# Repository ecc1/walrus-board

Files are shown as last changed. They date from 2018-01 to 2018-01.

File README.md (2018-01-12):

# Walrus Board

Walrus is an open-source platform for battery-powered sub-GHz and 2.4 GHz radio communication

### Dual Radios

Walrus has two radios, accessed over SPI:

* [RFM69HCW transceiver](http://www.hoperf.com/rf_transceiver/modules/RFM69HCW.html)
  for 900 MHz (also usable at 433 MHz)
* [CC2500 transceiver](http://www.ti.com/product/CC2500)
  for 2.4 GHz

### Designed for Raspberry Pi Zero W

* Raspberry Pi Zero form factor
* 40-pin Raspberry Pi GPIO connector
* HAT EEPROM

Walrus board connected to Raspberry Pi Zero W

### Battery Power Management

* JST PH 2.0mm connector for 3.7 V LiPo battery
* 500 mA battery charging when Raspberry Pi is connected to 5 V via micro-USB
* hard power-off via pushbutton or GPIO disconnects battery from Raspberry Pi
* programmable power-on via RTC alarm

### Other Peripherals

Walrus has the following I2C devices:

* Real-Time Clock (M41T62LC) with power-on alarm
* Analog-Digital Converter (ADS1015) for battery voltage and charge current measurement
* 3-axis Accelerometer (LIS3DH) with single and double-tap detection

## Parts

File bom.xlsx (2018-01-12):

Quantity | DNI | Designator | Description | Comment | Case | Mfg1 | Mfg1PartNumber | Distributor | MDLPartNumber
1 |  | C1 | Ceramic Chip Capacitor | 1.0µF 16V X7R | 1608(0603) | Taiyo Yuden | EMK107B7105KA-T | https://www.digikey.com/product-detail/en/taiyo-yuden/EMK107B7105KA-T/587-1241-1-ND/931018 | CAP_000045
2 |  | C8, C9 | Ceramic Chip Capacitor | 4.7µF 6.3V X5R | 1005(0402) | Murata | GRM155R60J475ME87D | https://www.digikey.com/product-detail/en/murata-electronics-north-america/GRM155R60J475ME87D/490-5408-1-ND/2175215 | CAP_000063
1 |  | C11 | Ceramic Chip Capacitor | 1.0µF 10V X5R | 1005(0402) | AVX | 0402ZD105KAT2A | https://www.digikey.com/product-detail/en/avx-corporation/0402ZD105KAT2A/478-4596-1-ND/1645907 | CAP_000094
2 |  | C2, C5 | Ceramic Chip Capacitor | 2.2µF 16V X5R | 1005(0402) | TDK | C1005X5R1C225K050BC | https://www.digikey.com/product-detail/en/tdk-corporation/C1005X5R1C225K050BC/445-9085-1-ND/3661600 | CAP_000166
2 |  | C20, C21 | Ceramic Chip Capacitor | 15pF 50V C0G/NP0 | 1005(0402) | AVX | 04025A150GAT2A | https://www.digikey.com/product-detail/en/avx-corporation/04025A150GAT2A/478-5268-1-ND/1950935 | CAP_000179
2 |  | C412, C512 | Ceramic Chip Capacitor | 47pF 50V C0G/NP0 | 1005(0402) | Kemet | C0402C470K5GACTU | https://www.digikey.com/product-detail/en/kemet/C0402C470K5GACTU/399-7796-1-ND/3471519 | CAP_000193
2 |  | C121, C131 | Ceramic Chip Capacitor | 100pF 50V C0G/NP0 | 1005(0402) | Murata | GRM1555C1H101JA01D | https://www.digikey.com/product-detail/en/murata-electronics-north-america/GRM1555C1H101JA01D/490-5922-1-ND/3721279 | CAP_000202
1 |  | C123 | Ceramic Chip Capacitor | 1.8pF 50V C0G/NP0 | 1005(0402) | Murata | GRM1555C1H1R8CA01D | https://www.digikey.com/product-detail/en/murata-electronics-north-america/GRM1555C1H1R8CA01D/490-5898-1-ND/3569084 | CAP_000204
1 |  | C124 | Ceramic Chip Capacitor | 1.5pF 50V C0G/NP0 | 1005(0402) | Murata | GRM1555C1H1R5CA01D | https://www.digikey.com/product-detail/en/murata-electronics-north-america/GRM1555C1H1R5CA01D/490-5891-1-ND/3481884 | CAP_000205
2 |  | C122, C132 | Ceramic Chip Capacitor | 1.0pF 50V C0G/NP0 | 1005(0402) | Murata | GRM1555C1H1R0CA01D | https://www.digikey.com/product-detail/en/murata-electronics-north-america/GRM1555C1H1R0CA01D/490-3199-1-ND/702740 | CAP_000206
3 |  | C91, C151, C181 | Ceramic Chip Capacitor | 220pF 50V X7R | 1005(0402) | Murata | GRM155R71H221KA01D | https://www.digikey.com/product-detail/en/murata-electronics-north-america/GRM155R71H221KA01D/490-1298-1-ND/587937 | CAP_000207
12 |  | C3, C4, C6, C7, C10, C12, C13, C14, C41, C51, C111, C141 | Ceramic Chip Capacitor | 0.1µF 10V X7R | 1005(0402) | Murata | GRM155R71A104KA01D | https://www.digikey.com/product-detail/en/murata-electronics-north-america/GRM155R71A104KA01D/490-6321-1-ND/3845518 | CAP_000208
1 | ♦ | J5 | KK 100 HEADER ASSY FLAT VERTICAL BREAKAWAY, 1X2 | 22-28-4023 |  | Molex | 22-28-4023 |  | CONN_000017
2 |  | J1, J2 | Ultra Small Surface Mount Coaxial Connectors - 1.9mm or 2.4mm Mated Height | U.FL-R-SMT-1 |  | Hirose | U.FL-R-SMT-1 | https://www.digikey.com/product-detail/en/hirose-electric-co-ltd/U.FL-R-SMT-1(10)/H11891CT-ND/2504612 | CONN_000064
1 |  | J4 | PH CONNECTOR/2.0MM Pitch Side Entry | S2B-PH-SM4-TB |  | JST | S2B-PH-SM4-TB | https://www.digikey.com/product-detail/en/jst-sales-america-inc/S2B-PH-SM4-TB(LF)(SN)/455-1749-1-ND/926846 | CONN_000190
1 | ♦ | J3 | 0.100" Tiger Beam™ Cost-effective Single Beam Socket Strip | HLE-120-02-G-DV-A |  | Samtec | HLE-120-02-G-DV-A |  | CONN_000192
8 |  | D1, D2, D3, D4, D5, D7, D10, D11 | Schottky Barrier Diode | RB520S30T1G | SOD-523 | ON Seminconductor | RB520S30T1G | https://www.digikey.com/product-detail/en/on-semiconductor/RB520S30T1G/RB520S30T1GOSCT-ND/964626 | DIOD_000001
1 |  | D9 | Surface Mounting Chip LED | BLUE | 1608(0603) | Lite-On | LTST-C190TBKT | https://www.digikey.com/product-detail/en/lite-on-inc/LTST-C190TBKT/160-1646-1-ND/573586 | DIOD_000059
1 |  | D6 | Surface Mounting Chip LED | GREEN | 1608(0603) | Lite-On | LTST-C190KGKT | https://www.digikey.com/product-detail/en/lite-on-inc/LTST-C190KGKT/160-1435-1-ND/386814 | DIOD_000061
1 |  | D8 | Surface Mounting Chip LED | RED | 1608(0603) | Lite-On | LTST-C190CKT | https://www.digikey.com/product-detail/en/lite-on-inc/LTST-C190CKT/160-1181-1-ND/269253 | DIOD_000068
1 |  | FB1 | GHz Noise Suppression Chip Ferrite Bead | 1000ohms ±25% @100MHz | 1005(0402) | Murata | BLM15HG102SN1D | https://www.digikey.com/product-detail/en/murata-electronics-north-america/BLM15HG102SN1D/490-3999-1-ND/1016259 | FB_000009
3 | ♦ | FD1, FD2, FD3 | Fiducial, PCB Printed Copper Feature | Fiducial, Single Side, 0.75mm Land |  |  |  |  | FD_000001
1 |  | F1 | POLY-FUSE® Resettable PTC, Surface Mount > LoRho Series | 0.75A Hold,1.5A Trip | 1608(0603) | Littelfuse | 0603L075SLYR | https://www.digikey.com/product-detail/en/littelfuse-inc/0603L075SLYR/F5777CT-ND/3661919 | FUSE_000007
1 |  | U9 | MEMS digital output motion sensor: ultra low-power high performance 3-axes “nano” accelerometer | LIS3DH | LGA-16 | STMicroelectronics | LIS3DH | https://www.digikey.com/product-detail/en/stmicroelectronics/LIS3DHTR/497-10613-1-ND/2334355 | IC_000038
1 |  | U5 | USB-FRIENDLY LITHIUM-ION BATTERY CHARGER AND POWER-PATH MANAGEMENT IC | bq24232 | QFN16 | Texas Instruments | BQ24232RGT | https://www.digikey.com/product-detail/en/texas-instruments/BQ24232RGTR/296-41207-1-ND/5222663 | IC_000195
1 |  | U3 | Ultra-Small, Low-Power, I2C-Compatible, 3.3-kSPS, 12-Bit ADC With Internal Reference, Oscillator, and Programmable Comparator | ADS1015 | X2QFN | Texas Instruments | ADS1015IRUGR,ADS1015IRUGT | https://www.digikey.com/product-detail/en/texas-instruments/ADS1015IRUGR/296-43557-1-ND/5864781 | IC_000284
1 |  | U2 | ISM TRANSCEIVER MODULE | RFM69HCW | MODULE | HopeRF | RFM69HCW | https://www.sparkfun.com/products/13909 | IC_000286
1 |  | U1 | Low-Cost Low-Power 2.4 GHz RF Transceiver | CC2500 | QFN20 | Texas Instruments | CC2500RGP,CC2500RGPR | https://www.digikey.com/product-detail/en/texas-instruments/CC2500RGPR/296-38562-1-ND/5034436 | IC_000287
1 |  | U7 | 2.6A Low Loss Ideal Diode in ThinSOT | LTC4411 | TSOT23-5 | Linear Technology | LTC4411ES5 | https://www.digikey.com/product-detail/en/linear-technology/LTC4411ES5-TRMPBF/LTC4411ES5-TRMPBFCT-ND/1754256 | IC_000293
1 |  | U6 | Pushbutton On/Off Controller with Automatic Turn-On | LTC2955T-2 | TSOT23-8 | Linear Technology | TC2955CTS8-2#TRMPBF | https://www.digikey.com/product-detail/en/linear-technology/LTC2955CTS8-2-TRMPBF/LTC2955CTS8-2-TRMPBFCT-ND/3065187 | IC_000294
1 |  | U4 | Low-power serial real-time clock (RTCs) with alarm | M41T62LC | LCC-8 | STMicroelectronics | M41T62LC6F | https://www.digikey.com/product-detail/en/stmicroelectronics/M41T62LC6F/497-11275-1-ND/2673274 | IC_000295
1 |  | U8 | 32-Kb I2C CMOS Serial EEPROM | CAT24C32 | UDFN-8 | ON Seminconductor | CAT24C32HU4I−GT3 | https://www.digikey.com/product-detail/en/on-semiconductor/CAT24C32HU4I-GT3/CAT24C32HU4I-GT3OSCT-ND/4927901 | IC_000300
3 |  | L121, L122, L131 | Surface Mount Multilayer RF Chip Inductors | 1.2nH ±0.3nH | 1005(0402) | Murata | LQG15HS1N2S02D | https://www.digikey.com/product-detail/en/murata-electronics-north-america/LQG15HS1N2S02D/490-2611-1-ND/662891 | IND_000048
3 |  | R13, R17, R20 | Chip Resistor, Thick Film | 4.99K ±1% | 1005(0402) | Vishay/Dale | CRCW04024K99FKED | https://www.digikey.com/product-detail/en/vishay-dale/CRCW04024K99FKED/541-4.99KLCT-ND/1183202 | RES_000003
2 |  | R7, R14 | Chip Resistor, Thick Film | 10.0K ±1% | 1005(0402) | Vishay/Dale | CRCW040210K0FKED | https://www.digikey.com/product-detail/en/vishay-dale/CRCW040210K0FKED/541-10.0KLCT-ND/1183237 | RES_000005
4 | ♦ | R8, R9, R10, R12 | Chip Resistor, Thick Film | DNP | 1005(0402) |  |  |  | RES_000064
4 |  | R1, R2, R22, R23 | Chip Resistor, Thick Film | 100K ±1% | 1005(0402) | Vishay/Dale | CRCW0402100KFKED | https://www.digikey.com/product-detail/en/vishay-dale/CRCW0402100KFKED/541-100KLCT-ND/1183351 | RES_000067
1 |  | R15 | Chip Resistor, Thick Film | 680K ±1% | 1005(0402) | Vishay/Dale | CRCW0402680KFKED | https://www.digikey.com/product-detail/en/vishay-dale/CRCW0402680KFKED/541-680KLCT-ND/1183446 | RES_000103
1 |  | R21 | Chip Resistor, Thick Film | 22.0 ±1% | 1005(0402) | Vishay/Dale | CRCW040222R0FKED | https://www.digikey.com/product-detail/en/vishay-dale/CRCW040222R0FKED/541-22.0LCT-ND/1182931 | RES_000158
1 |  | R16 | Chip Resistor, Thick Film | 240K ±1% | 1005(0402) | Vishay/Dale | CRCW0402240KFKED | https://www.digikey.com/product-detail/en/vishay-dale/CRCW0402240KFKED/541-240KLCT-ND/1183392 | RES_000165
1 |  | R171 | Chip Resistor, Thick Film | 56K ±1% | 1005(0402) | Vishay/Dale | CRCW040256K0FKED | https://www.digikey.com/product-detail/en/vishay-dale/CRCW040256K0FKED/541-56.0KLCT-ND/1183322 | RES_000185
1 |  | R4 | Chip Resistor, Thick Film | 3.40K ±1% | 1005(0402) | Vishay/Dale | CRCW04023K40FKED | https://www.digikey.com/product-detail/en/vishay-dale/CRCW04023K40FKED/541-3.40KLCT-ND/1183182 | RES_000253
1 |  | R19 | Chip Resistor, Thick Film | 160 ±1% | 1005(0402) | Vishay/Dale | CRCW0402160RFKED | https://www.digikey.com/product-detail/en/vishay-dale/CRCW0402160RFKED/541-160LCT-ND/1183030 | RES_000286
1 |  | R18 | Chip Resistor, Thick Film | 191 ±1% | 1005(0402) | Vishay/Dale | CRCW0402191RFKED | https://www.digikey.com/product-detail/en/vishay-dale/CRCW0402191RFKED/541-191LCT-ND/1183039 | RES_000287
7 |  | R5, R6, R11, R24, R25, R26, R27 | Chip Resistor, Thick Film | 1.8K ±1% | 1005(0402) | Vishay/Dale | CRCW04021K80FKED | https://www.digikey.com/product-detail/en/vishay-dale/CRCW04021K80FKED/541-1.80KLCT-ND/1183150 | RES_000288
1 |  | R3 | Chip Resistor, Thick Film | 3.6K ±1% | 1005(0402) | Vishay/Dale | CRCW04023K60FKED | https://www.digikey.com/product-detail/en/vishay-dale/CRCW04023K60FKED/541-3.60KLCT-ND/1183185 | RES_000296
1 |  | S1 | KMR 2 Series Microminiature SMT Top Actuated | KMR221GLFS |  | C&K | KMR221GLFS | https://www.digikey.com/product-detail/en/c-k/KMR221GLFS/401-1427-1-ND/550466 | SWCH_000001
7 | ♦ | TP1, TP2, TP3, TP4, TP5, TP6, TP7 | Test Point | Test Point, Through Hole, 1.0mm Pad, 0.5mm Hole |  |  |  |  | TP_000015
1 |  | Q2 | Small Signal MOSFET | NTA4151PT1G | SOT416, SC75 | ON Seminconductor | NTA4151PT1G | https://www.digikey.com/product-detail/en/on-semiconductor/NTA4151PT1G/NTA4151PT1GOSCT-ND/687112 | TRAN_000001
2 |  | Q1, Q3 | Small Signal MOSFET | NTA7002NT1G | SOT416, SC75 | ON Seminconductor | NTA7002NT1G | https://www.digikey.com/product-detail/en/on-semiconductor/NTA7002NT1G/NTA7002NT1GOSCT-ND/1484663 | TRAN_000002
1 |  | Y1 | CERAMIC SMD CRYSTAL | 26.000MHz ±10ppm 10pF | XTAL5032 | Abracon | ABM3B-26.000MHZ-10-1-U-T | https://www.digikey.com/product-detail/en/abracon-llc/ABM3B-26.000MHZ-10-1-U-T/300-8219-1-ND/687912 | XTAL_000024

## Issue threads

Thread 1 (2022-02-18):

LIS3DH footprint

iceberg1369, 2022-02-18:
I would like to know do you have any trouble in soldering lis3dh by stencil and pick and place machine?

ecc1, 2022-02-18:
We used a contract assembly house to build the first (and only) run of Walrus boards. I don't think any of the components presented any difficulties.

Closed 2022-02-18.

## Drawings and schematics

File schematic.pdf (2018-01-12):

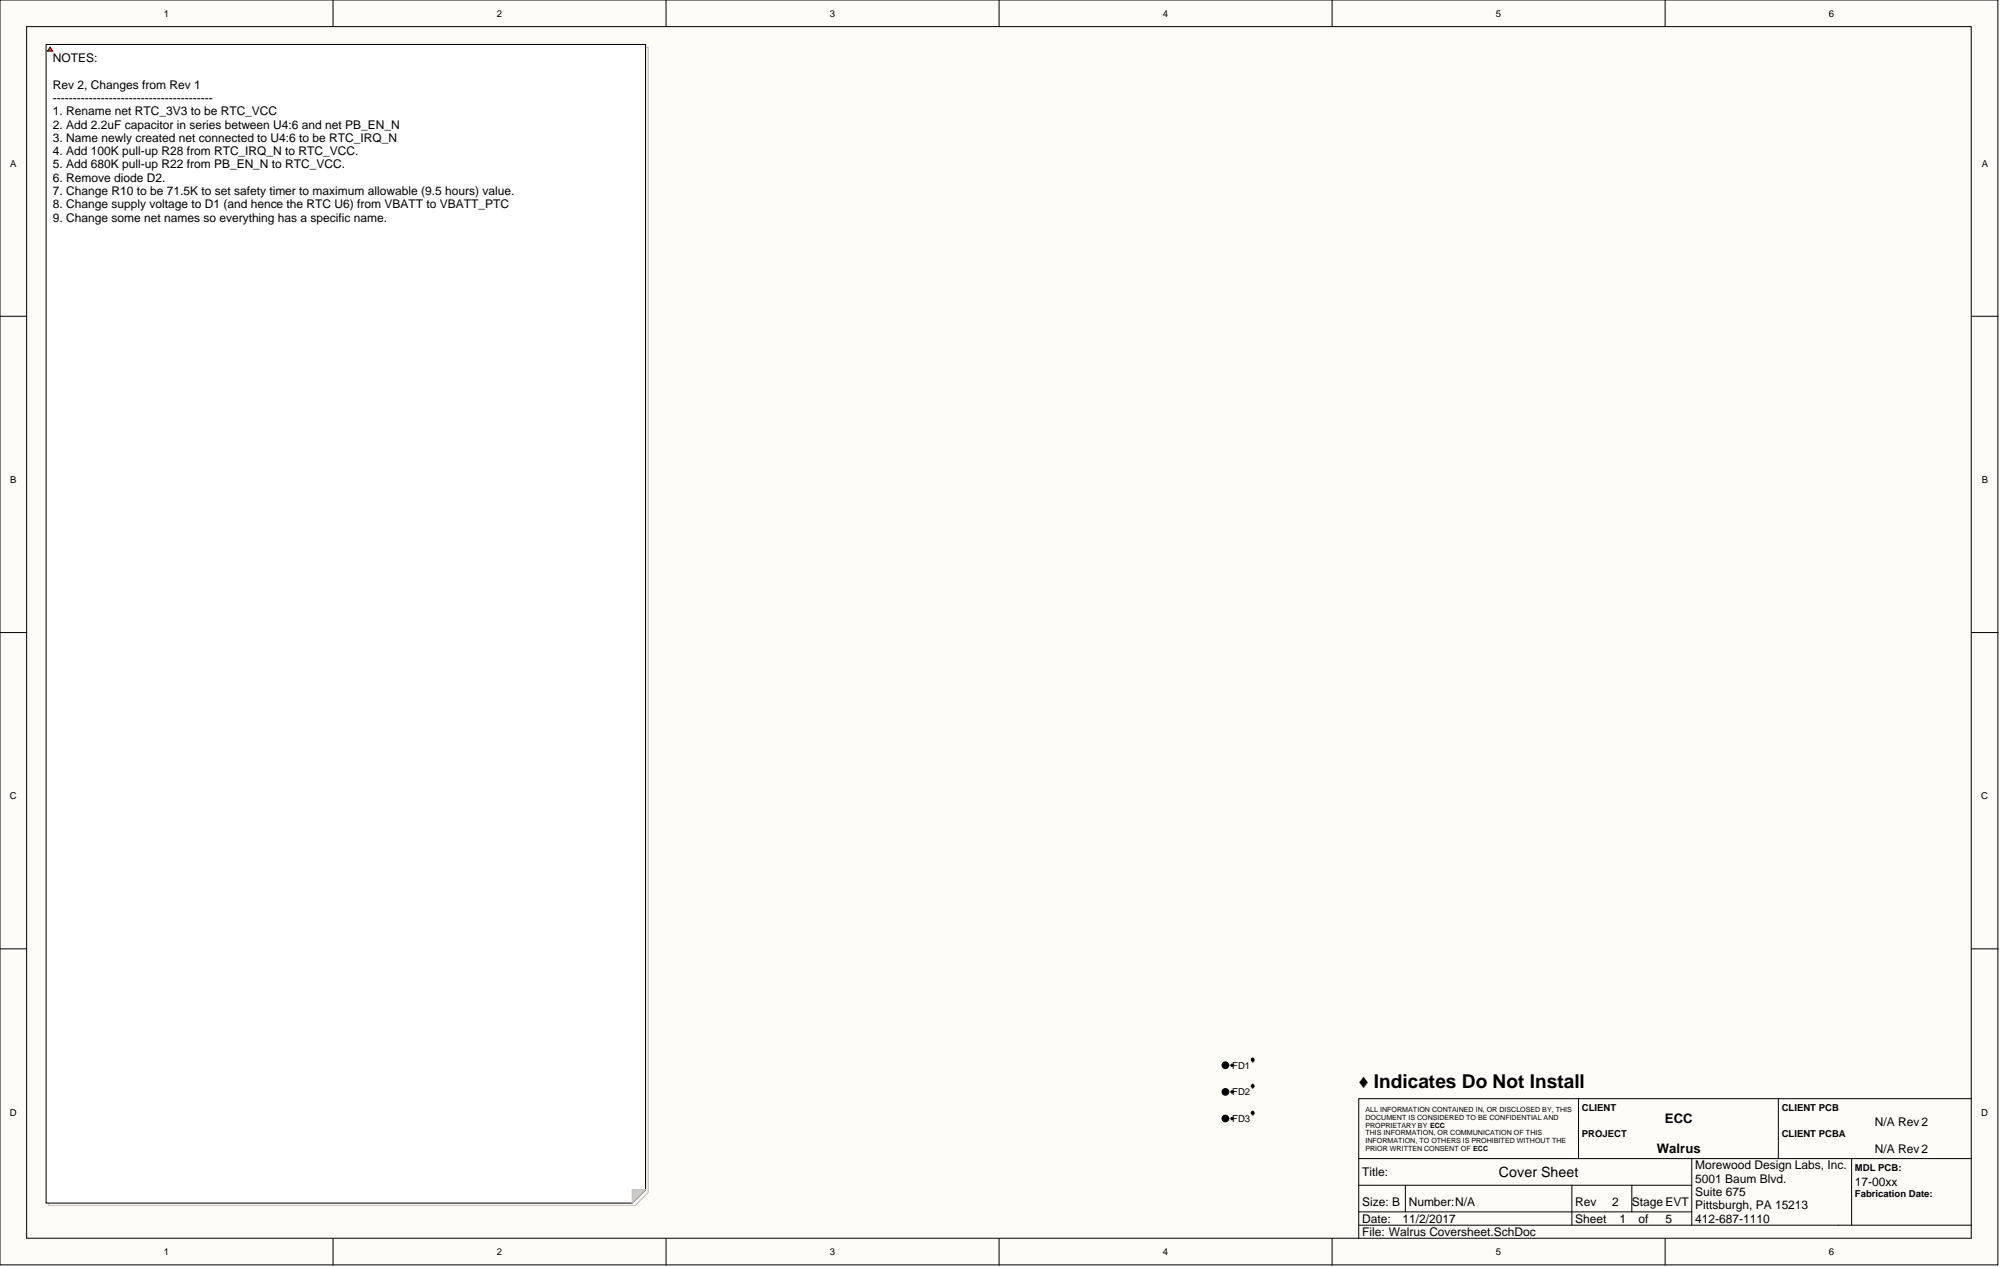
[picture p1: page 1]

Rev 2, Changes from Rev 1
1. Rename net RTC_3V3 to be RTC_VCC
2. Add 2.2uF capacitor in series between U4:6 and net PB_EN_N
3. Name newly created net connected to U4:6 to be RTC_IRQ_N
4. Add 100K pull-up R28 from RTC_IRQ_N to RTC_VCC.
5. Add 680K pull-up R22 from PB_EN_N to RTC_VCC.
6. Remove diode D2.
7. Change R10 to be 71.5K to set safety timer to maximum allowable (9.5 hours) value.
8. Change supply voltage to D1 (and hence the RTC U6) from VBATT to VBATT_PTC
9. Change some net names so everything has a specific name.

♦ Indicates Do Not Install

ALL INFORMATION CONTAINED IN, OR DISCLOSED BY, THIS PROPRIETARY BY DOCUMENT IS CONSIDERED TO BE CONFIDENTIAL AND ECC THIS INFORMATION, OR COMMUNICATION OF THIS INFORMATION, TO OTHERS IS PROHIBITED WITHOUT THE PRIOR WRITTEN CONSENT OF ECC | ECC CLIENT PROJECT Walrus | CLIENT PCB N/A CLIENT PCBA Rev 2 N/A Rev 2

Title: Cover Sheet | Morewood Design Labs, Inc. 5001 Baum Blvd. Suite 675 Pittsburgh, PA 15213 412-687-1110 | MDL PCB: 17-00xx Fabrication Date:

Size: B | Number: N/A | Rev 2 | Stage EVT
Date: | | Sheet 1 of 5

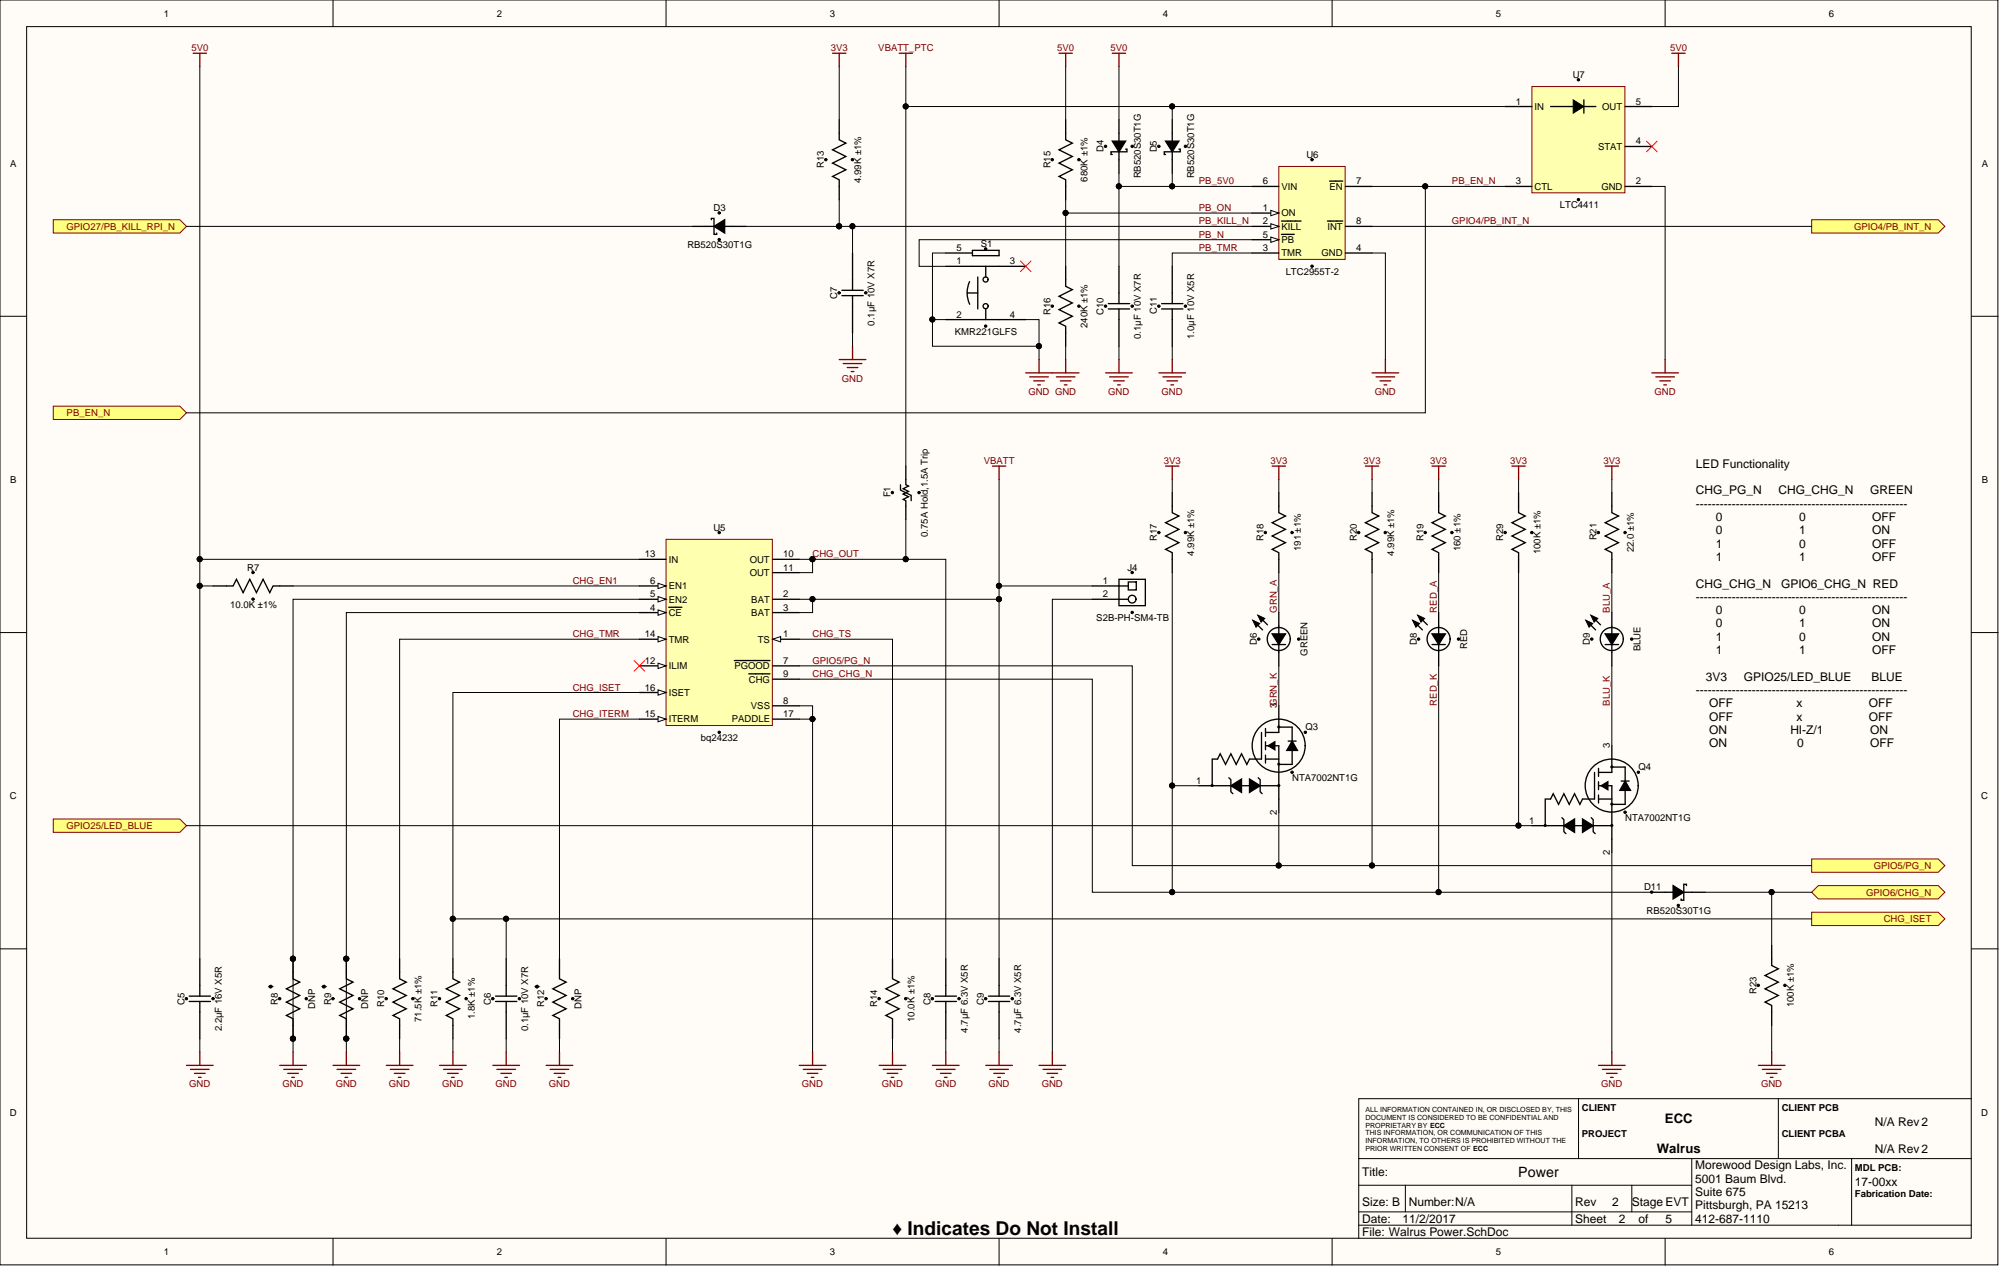
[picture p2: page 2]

GND | | PB_ON | INT | 8 ON 1

PB_KILL_N PB_N | KILL 2 PB 5

5 S1 | | PB_TMR | TMR 3

CE 4 | CHG_TS

CHG_TMR | TMR 14

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

Power

♦ Indicates Do Not Install

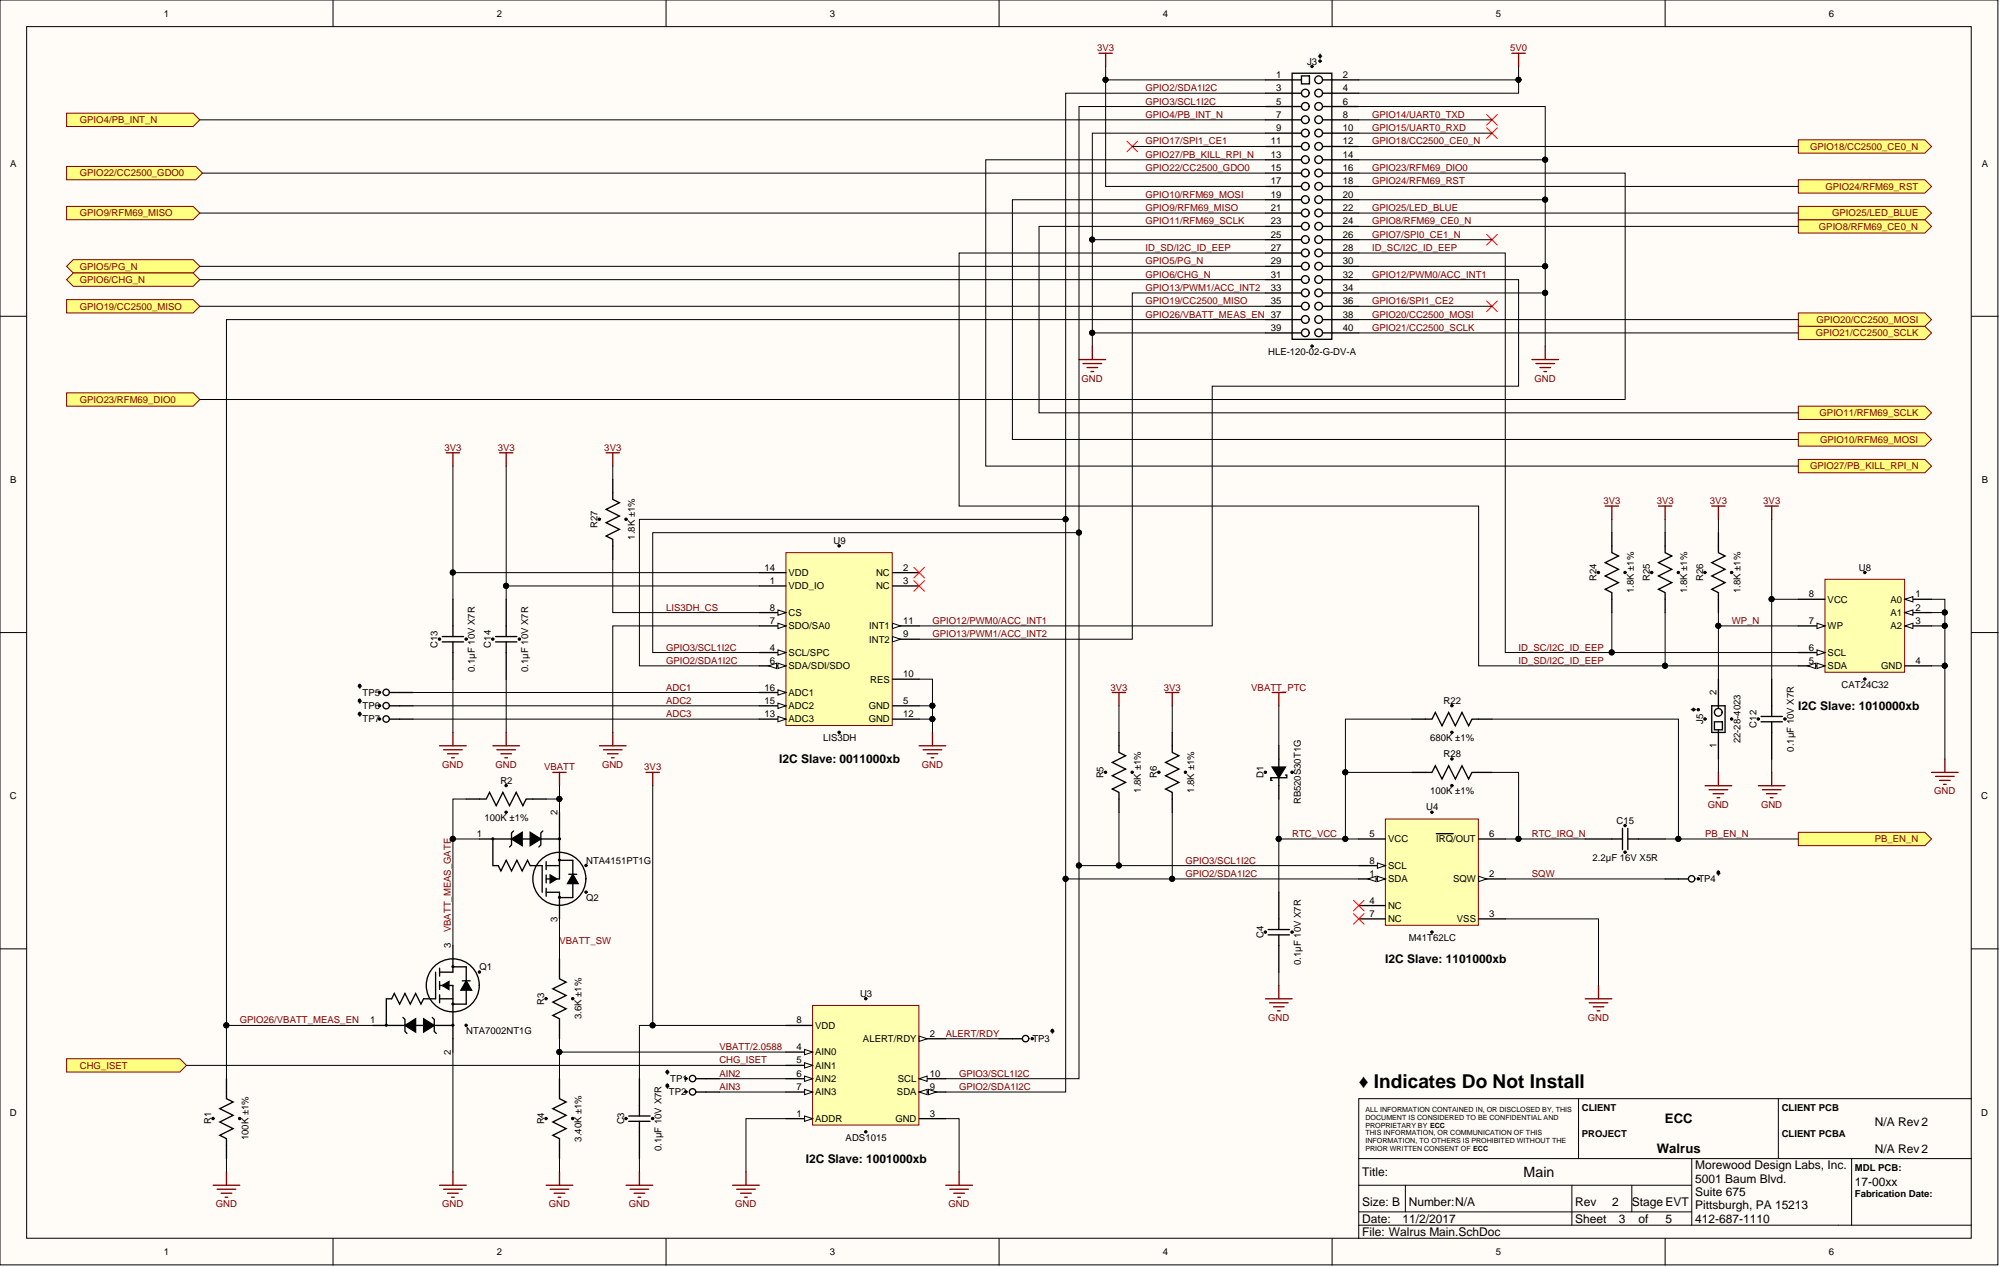
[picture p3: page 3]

GPIO2/SDA1I2C
GPIO3/SCL1I2C
GPIO4/PB_INT_N

GPIO17/SPI1_CE1 GPIO27/PB_KILL_RPI_N | 11

GPIO22/CC2500_GDO0 | 15 | 16 GPIO23/RFM69_DIO0

GPIO9/RFM69_MISO | 21 | | 22 GPIO25/LED_BLUE 24 GPIO8/RFM69_CE0_N
GPIO11/RFM69_SCLK | 23

ID_SD/I2C_ID_EEP | 27
GPIO5/PG_N | 29
GPIO6/CHG_N | 31
GPIO13/PWM1/ACC_INT2 | 33
GPIO19/CC2500_MISO | 35
GPIO26/VBATT_MEAS_EN | 37

GPIO3/SCL1I2C | SCL/SPC 4 | GPIO13/PWM1/ACC_INT2

ADC2 | ADC2 15
ADC3

♦ Indicates Do Not Install

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

Main

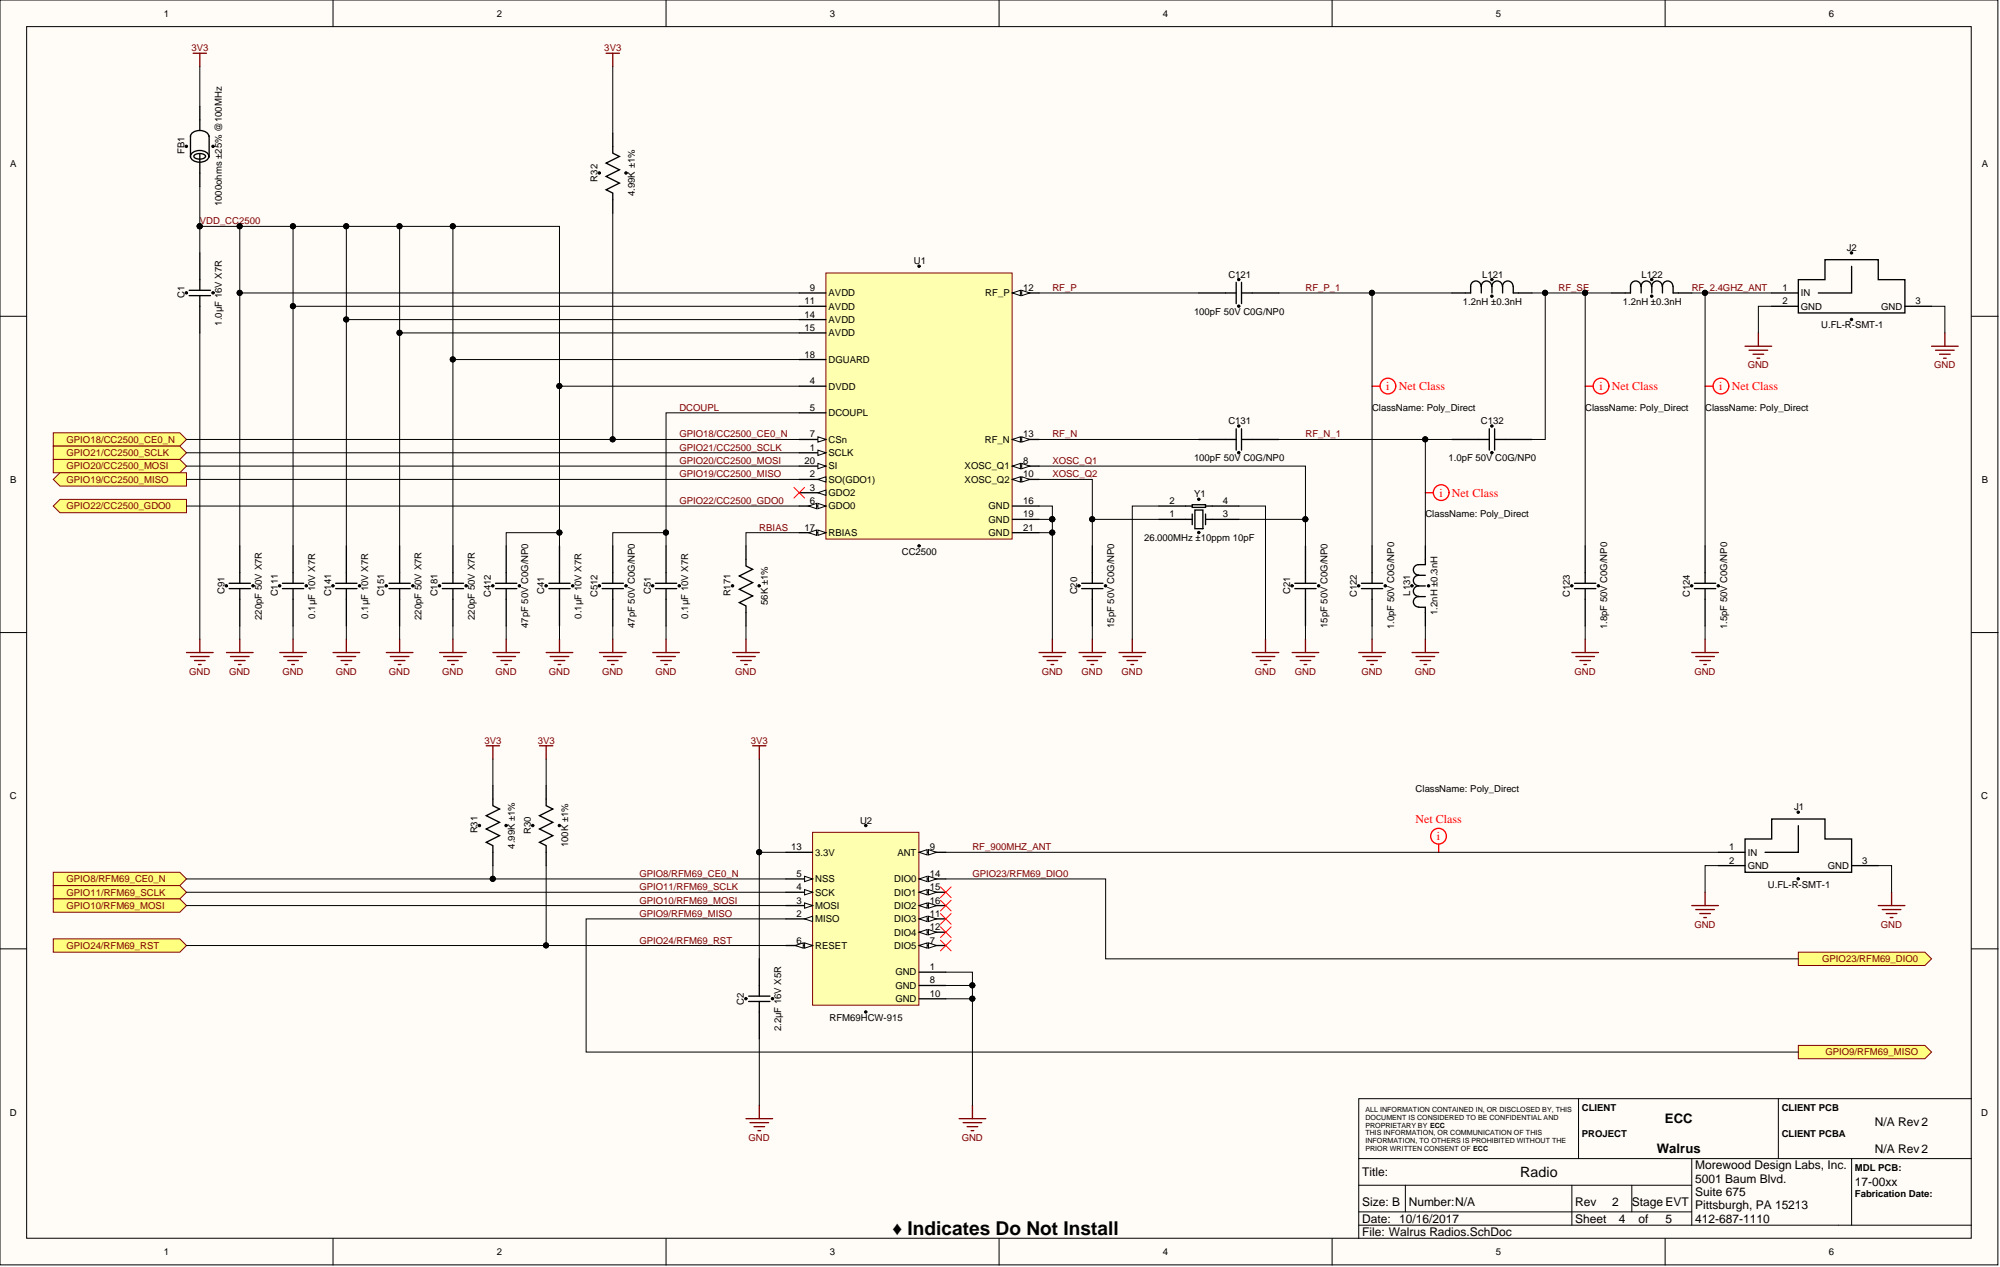
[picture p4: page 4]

AVDD 11
AVDD 14
AVDD 15

DGUARD 18

DVDD 4

DCOUPL | DCOUPL 5

GPIO18/CC2500_CE0_N | CSn 7
GPIO21/CC2500_SCLK | SCLK 1 | XOSC_Q1
GPIO20/CC2500_MOSI | SI 20

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

Radio

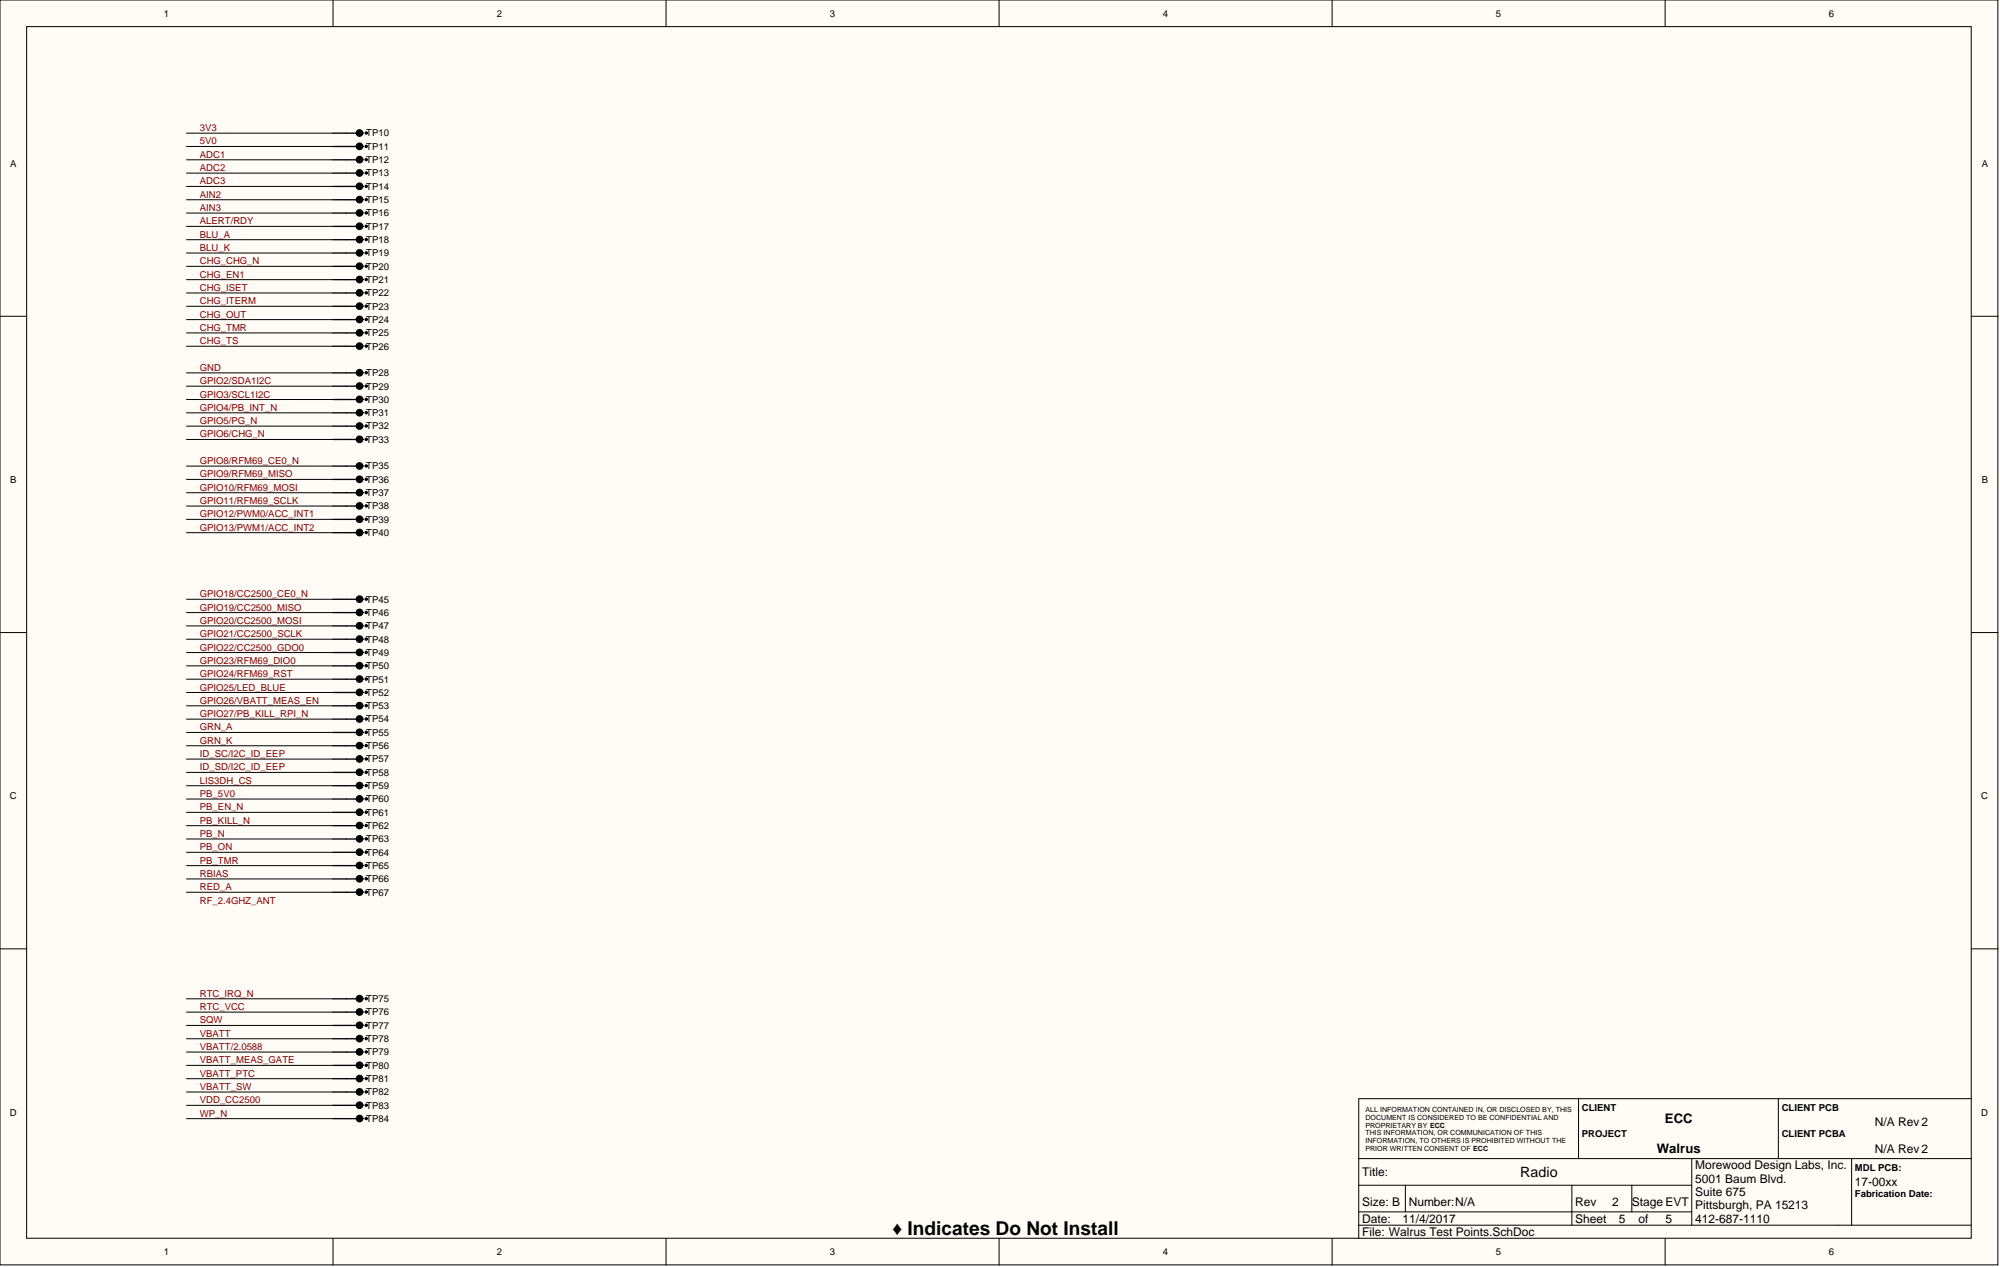
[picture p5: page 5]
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

Radio

Walrus Test Points.SchDoc

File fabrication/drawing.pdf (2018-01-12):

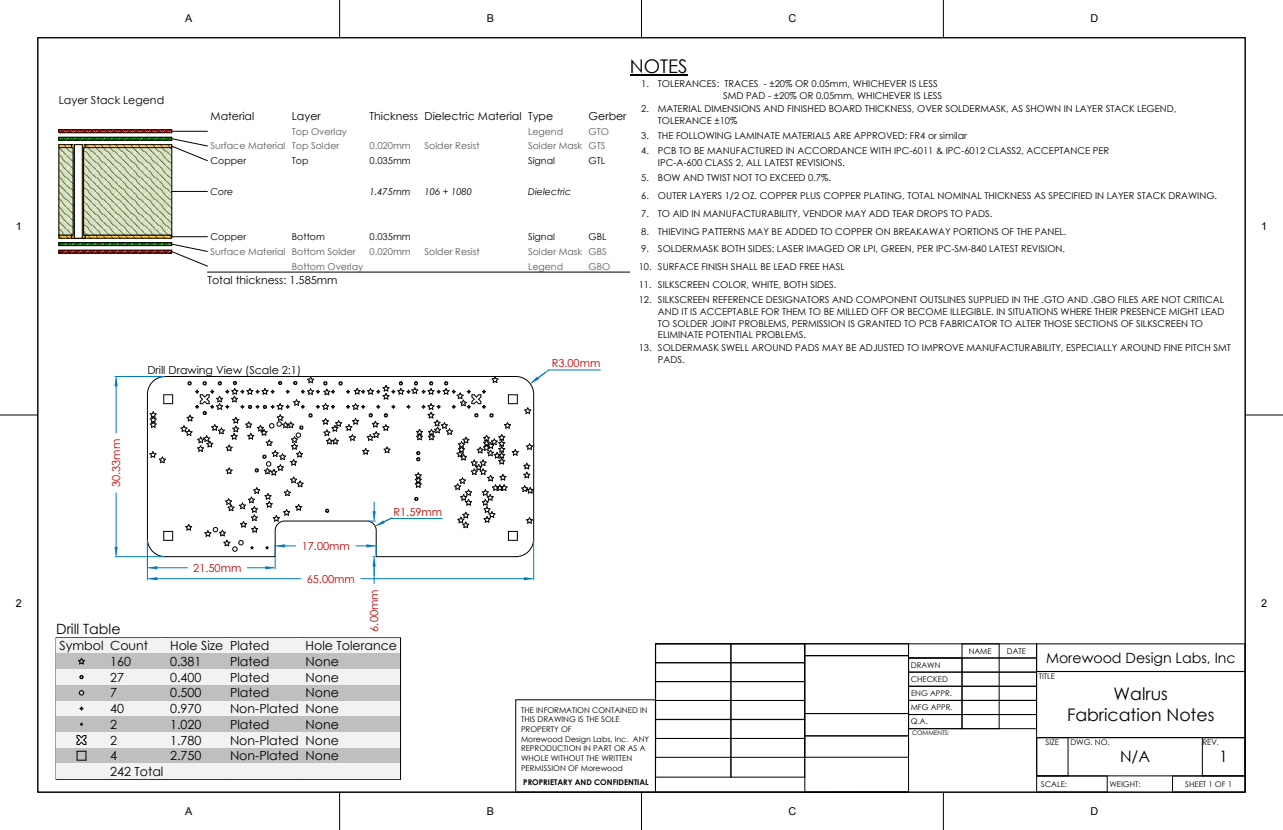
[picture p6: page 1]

TOLERANCES: TRACES - ±20% OR 0.05mm, WHICHEVER IS LESS

SMD PAD - ±20% OR 0.05mm, WHICHEVER IS LESS

MATERIAL DIMENSIONS AND FINISHED BOARD THICKNESS, OVER SOLDERMASK, AS SHOWN IN LAYER STACK LEGEND,
TOLERANCE ±10%
3. THE FOLLOWING LAMINATE MATERIALS ARE APPROVED: FR4 or similar
PCB TO BE MANUFACTURED IN ACCORDANCE WITH IPC-6011 & IPC-6012 CLASS2, ACCEPTANCE PER
IPC-A-600 CLASS 2, ALL LATEST REVISIONS.
5. BOW AND TWIST NOT TO EXCEED 0.7%.
6. OUTER LAYERS 1/2 OZ. COPPER PLUS COPPER PLATING, TOTAL NOMINAL THICKNESS AS SPECIFIED IN LAYER STACK DRAWING.
7. TO AID IN MANUFACTURABILITY, VENDOR MAY ADD TEAR DROPS TO PADS.
8. THIEVING PATTERNS MAY BE ADDED TO COPPER ON BREAKAWAY PORTIONS OF THE PANEL.
9. SOLDERMASK BOTH SIDES: LASER IMAGED OR LPI, GREEN, PER IPC-SM-840 LATEST REVISION.
10. SURFACE FINISH SHALL BE LEAD FREE HASL
11. SILKSCREEN COLOR, WHITE, BOTH SIDES.
SILKSCREEN REFERENCE DESIGNATORS AND COMPONENT OUTSLINES SUPPLIED IN THE .GTO AND .GBO FILES ARE NOT CRITICAL
AND IT IS ACCEPTABLE FOR THEM TO BE MILLED OFF OR BECOME ILLEGIBLE. IN SITUATIONS WHERE THEIR PRESENCE MIGHT LEAD
TO SOLDER JOINT PROBLEMS, PERMISSION IS GRANTED TO PCB FABRICATOR TO ALTER THOSE SECTIONS OF SILKSCREEN TO
ELIMINATE POTENTIAL PROBLEMS.
SOLDERMASK SWELL AROUND PADS MAY BE ADJUSTED TO IMPROVE MANUFACTURABILITY, ESPECIALLY AROUND FINE PITCH SMT
PADS.

Drill Drawing View (Scale 2:1)

Symbol | Count | Hole Size | Plated | Hole Tolerance

NAME | DATE | Morewood Design Labs, Inc

160 | 0.381 | Plated | None

DRAWN

THE INFORMATION CONTAINED IN
THIS DRAWING IS THE SOLE
PROPERTY OF
Morewood Design Labs, Inc. ANY
REPRODUCTION IN PART OR AS A
WHOLE WITHOUT THE WRITTEN
PERMISSION OF Morewood
PROPRIETARY AND CONFIDENTIAL

2 | 1.780 | Non-Plated | None
4 | 2.750 | Non-Plated | None
242 Total

SIZE | DWG. NO. N/A | REV. 1

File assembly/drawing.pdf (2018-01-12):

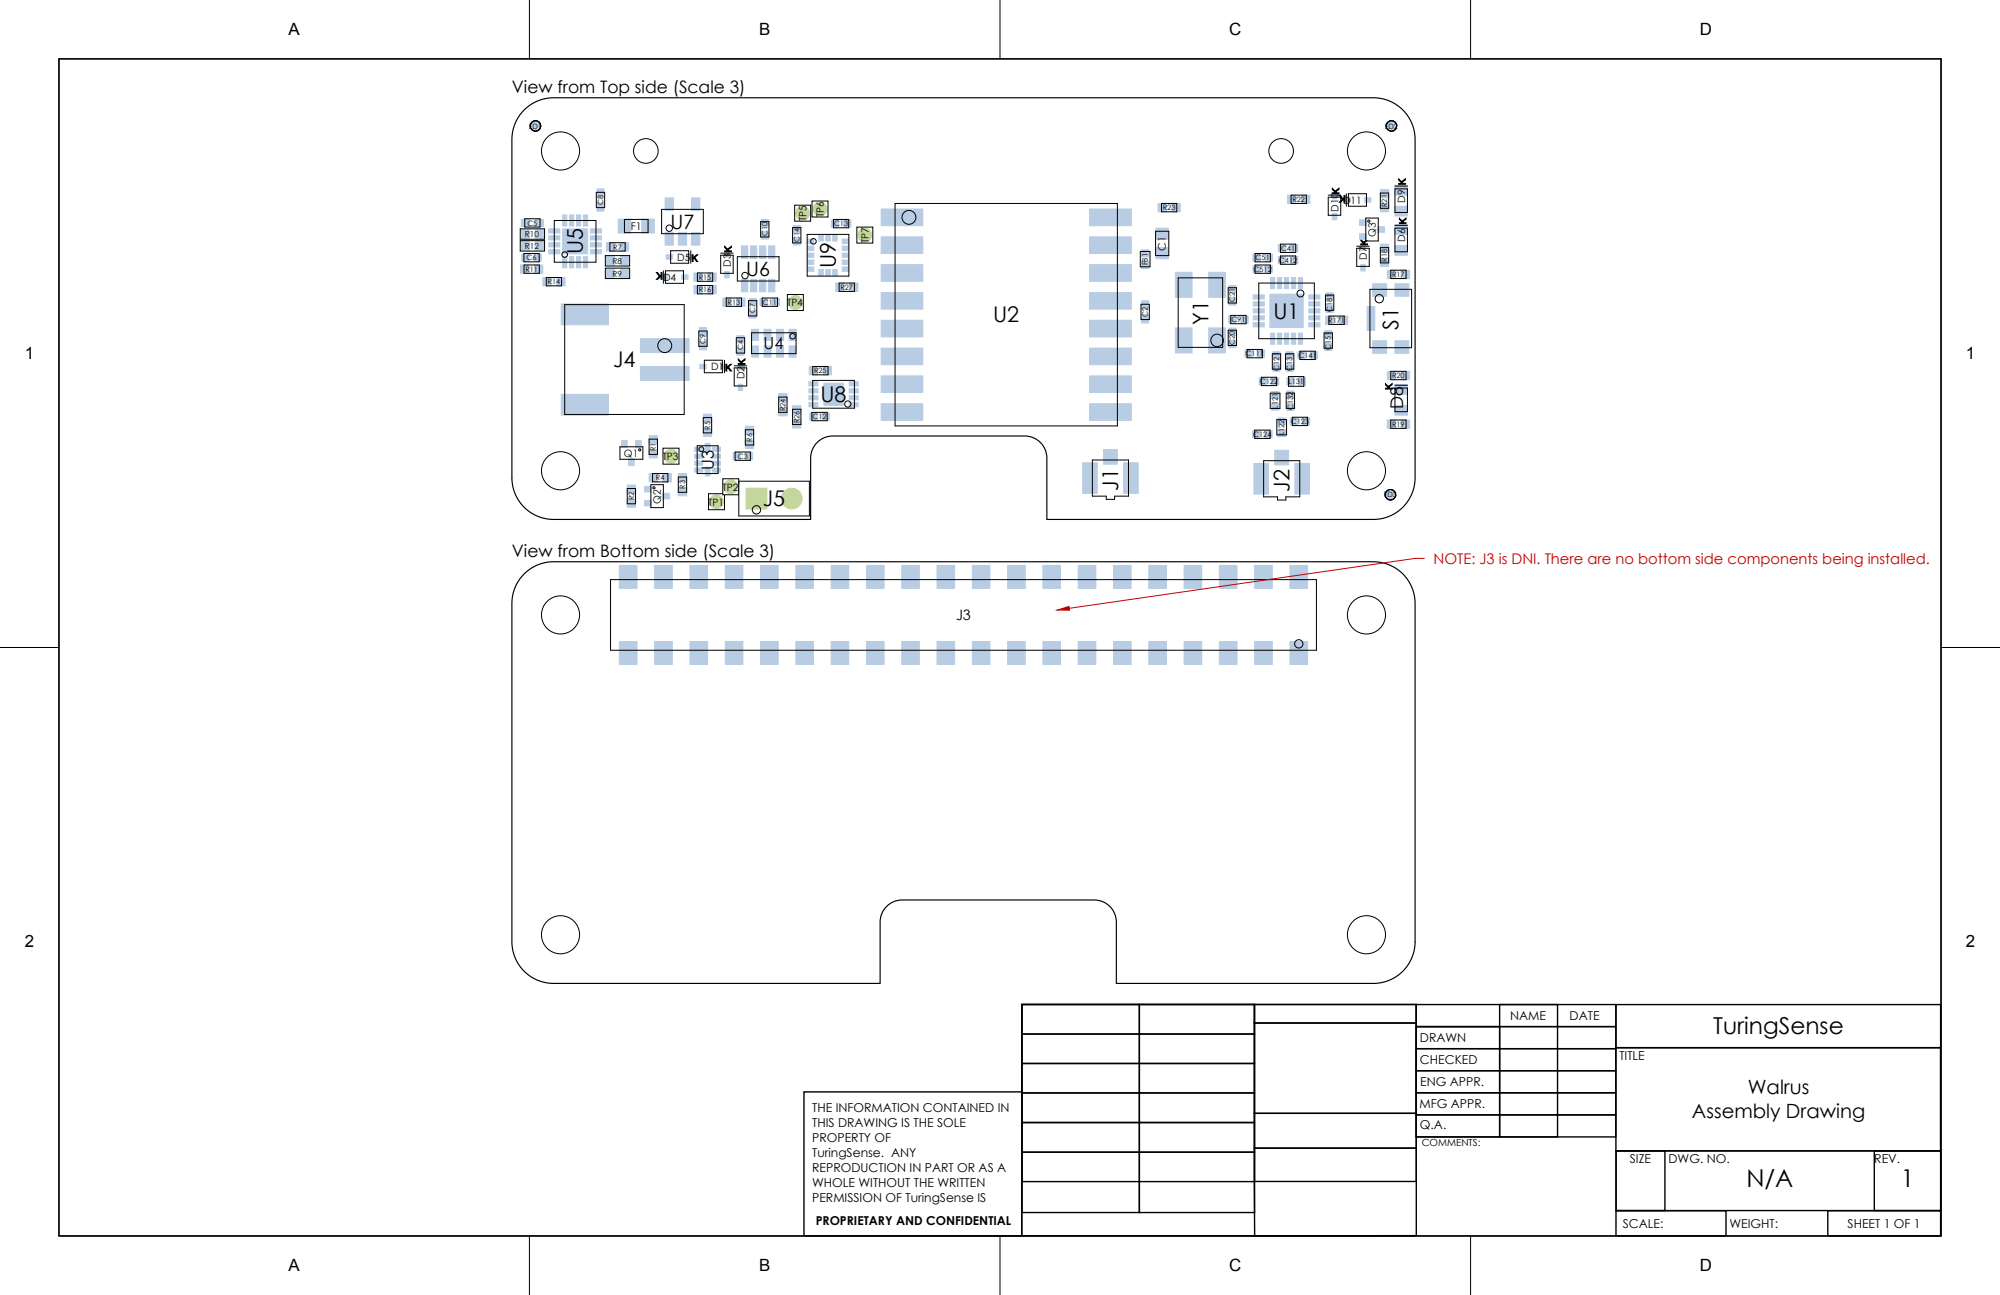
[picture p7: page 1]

View from Top side (Scale 3)

TP2
TP1

View from Bottom side (Scale 3)

NOTE: J3 is DNI. There are no bottom side components being installed.

NAME | DATE | TuringSense

DRAWN
CHECKED | | | TITLE Walrus Assembly Drawing
ENG APPR.

THE INFORMATION CONTAINED IN THIS DRAWING IS THE SOLE PROPERTY OF TuringSense. ANY REPRODUCTION IN PART OR AS A WHOLE WITHOUT THE WRITTEN PERMISSION OF TuringSense IS PROPRIETARY AND CONFIDENTIAL | | MFG APPR.

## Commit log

2018-01-12 Design files for Walrus prototype (Revision 1)
    [Walrus Coversheet.SchDoc, Walrus Main.SchDoc, Walrus Power.SchDoc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]
2018-01-12 Revision 2 schematic
